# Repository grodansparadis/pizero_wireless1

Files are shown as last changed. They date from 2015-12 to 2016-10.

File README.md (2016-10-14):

<h1>Pizero Wireless 1 HAT</h1>

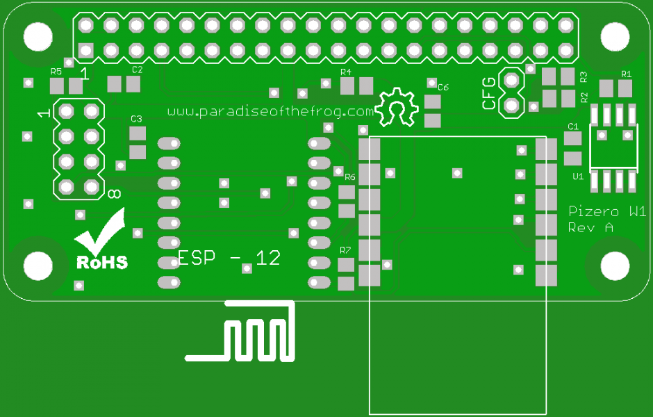
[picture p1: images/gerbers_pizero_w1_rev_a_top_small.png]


The Pizero Wireless 1 HAT is a PCB module that can host either

<ul>
<li>One nrf24L10 wireless tranceiver.</li>
<li>One Microchip MV24J40A/B IEEE 802.11.14 tranceiver module.</li>
<li>One ESP8288 WiFi module.</li>
</ul>

You can order the module from the <a href="http://www.frogshop.se">FrogShop</a>.

<hr>

This project is licensed under the 
<a href="http://creativecommons.org/licenses/by-nc-sa/3.0/">Creative Commons open source license Attribution-NonCommercial-ShareAlike 3.0 Unported</a>. 
Other license options are available by conacting <a href="malto:info@grodansparadis.com">Paradis of the Frog AB</a>

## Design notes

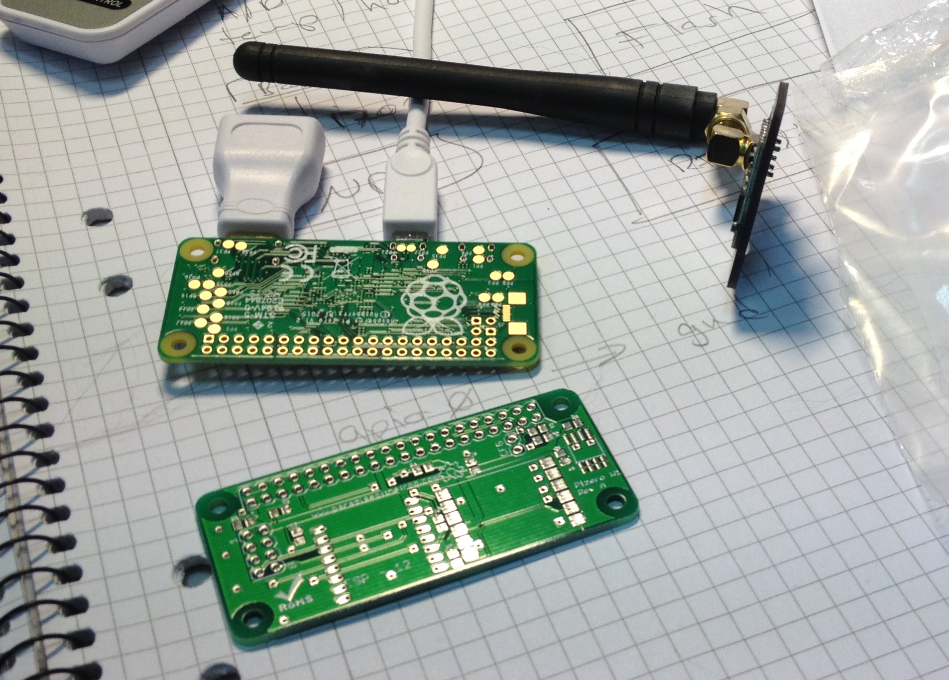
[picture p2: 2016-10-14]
images/prototype_arrival.png

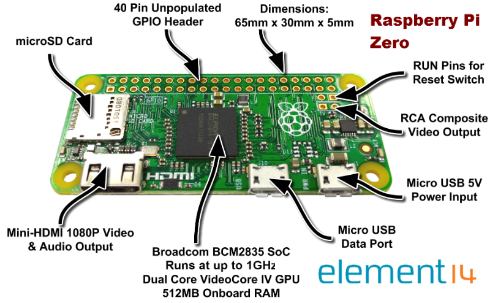
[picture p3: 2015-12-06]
docs/Pi+Zero+Features+Graphic+-+Small.png

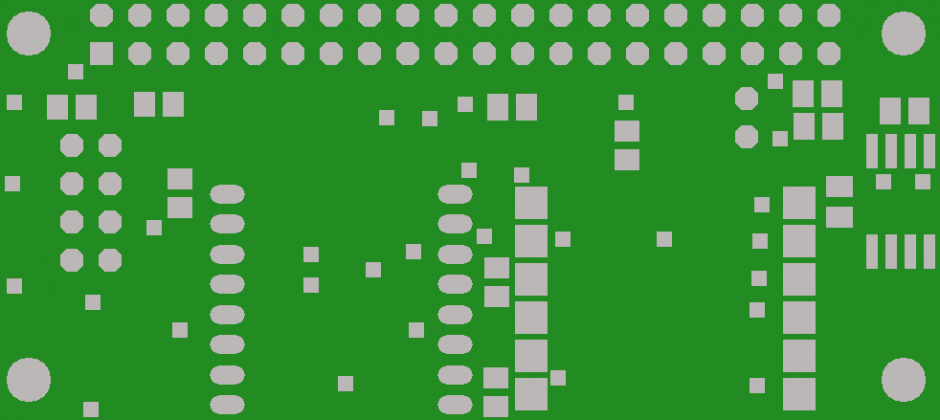
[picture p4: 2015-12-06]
images/gerbers_pizero_w1_rev_a_gts_small.png

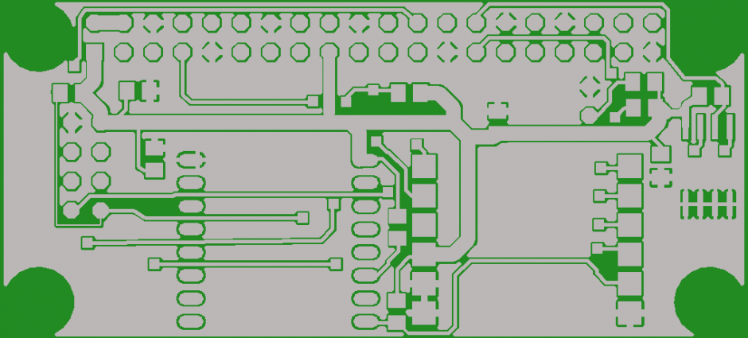
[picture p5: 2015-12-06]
images/gerbers_pizero_w1_rev_a_gtl_small.png

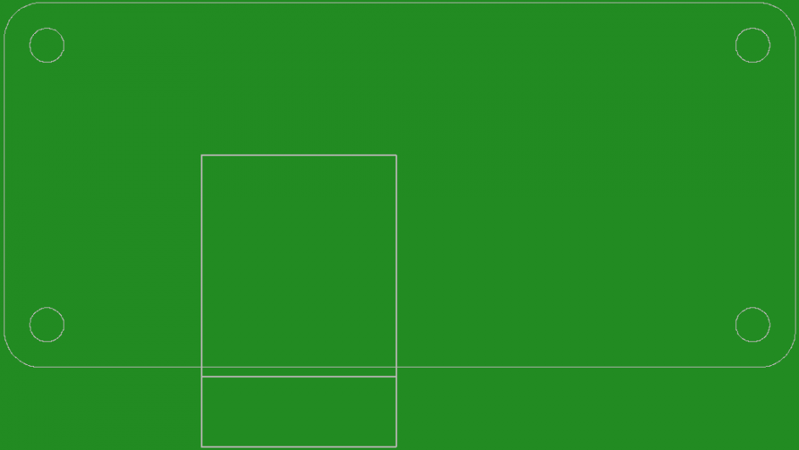
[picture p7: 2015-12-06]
images/gerbers_pizero_w1_rev_a_gbo_small.png

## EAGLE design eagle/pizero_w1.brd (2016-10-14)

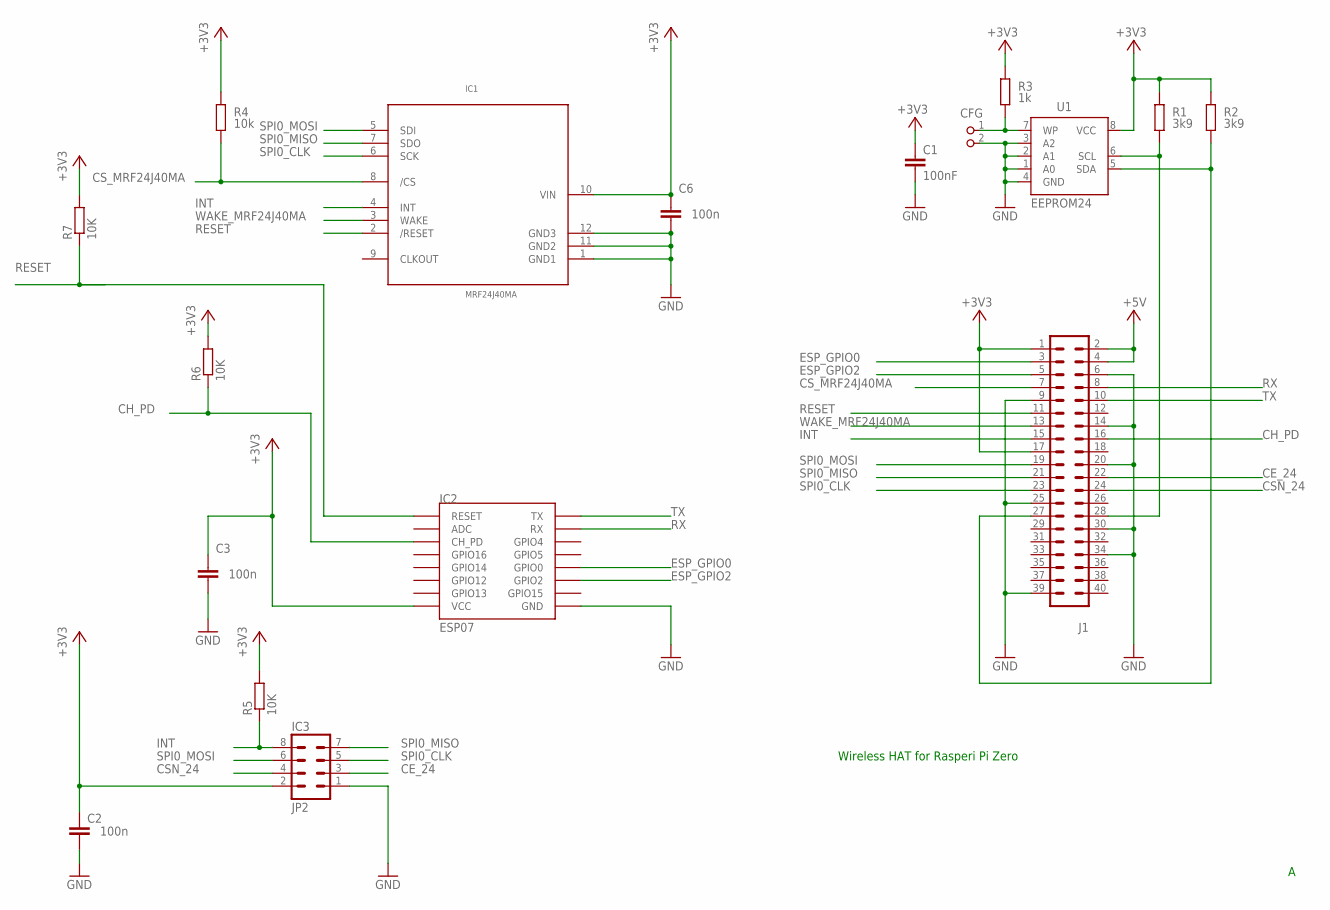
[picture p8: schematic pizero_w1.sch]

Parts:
C1: 100nF; C0805K
C2, C3, C6: 100n; C0805
CFG: PIN2_100; PIN_W_2
IC1: MRF24J40MA
IC2: ESP07; ESP12
IC3: JP2; MA04-2
J1: PIZERO_THROUGH_HOLE; PIZERO_THOUGH_HOLE
R1, R2: 3k9; M0805; TOLERANCE 5%
R3: 1k; M0805; TOLERANCE 5%
R4: 10k; M0805; TOLERANCE 5%
R5, R6, R7: 10K; R0805
U1: EEPROM24; SOIC8

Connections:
+3V3: C1.1, C2.1, C3.1, C6.1, IC1.10 (VIN), IC2.VCC, IC3.2, J1.1, J1.17, R1.2, R2.2, R3.2, R4.2, R5.2, R6.2, R7.2, U1.8 (VCC)
+5V: J1.2, J1.4
CE_24: IC3.3, J1.22
CH_PD: IC2.CH_PD, J1.16, R6.1
CSN_24: IC3.4, J1.24
CS_MRF24J40MA: IC1.8 (/CS), J1.7, R4.1
ESP_GPIO0: IC2.GPIO0, J1.3
ESP_GPIO2: IC2.GPIO2, J1.5
GND: C1.2, C2.2, C3.2, C6.2, CFG.2, IC1.1 (GND1), IC1.11 (GND2), IC1.12 (GND3), IC2.GND, IC3.1, J1.6, J1.9, J1.14, J1.20, J1.25, J1.30, J1.34, J1.39, U1.1 (A0), U1.2 (A1), U1.3 (A2), U1.4 (GND)
INT: IC1.4 (INT), IC3.8, J1.15, R5.1
unnamed: CFG.1, R3.1, U1.7 (WP)
RESET: IC1.2 (/RESET), IC2.RESET, J1.11, R7.1
RX: IC2.RX, J1.8
SCL: J1.28, R1.1, U1.6 (SCL)
SDA: J1.27, R2.1, U1.5 (SDA)
SPI0_CLK: IC1.6 (SCK), IC3.5, J1.23
SPI0_MISO: IC1.7 (SDO), IC3.7, J1.21
SPI0_MOSI: IC1.5 (SDI), IC3.6, J1.19
TX: IC2.TX, J1.10
WAKE_MRF24J40MA: IC1.3 (WAKE), J1.13

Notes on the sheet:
Wireless HAT for Rasperi Pi Zero

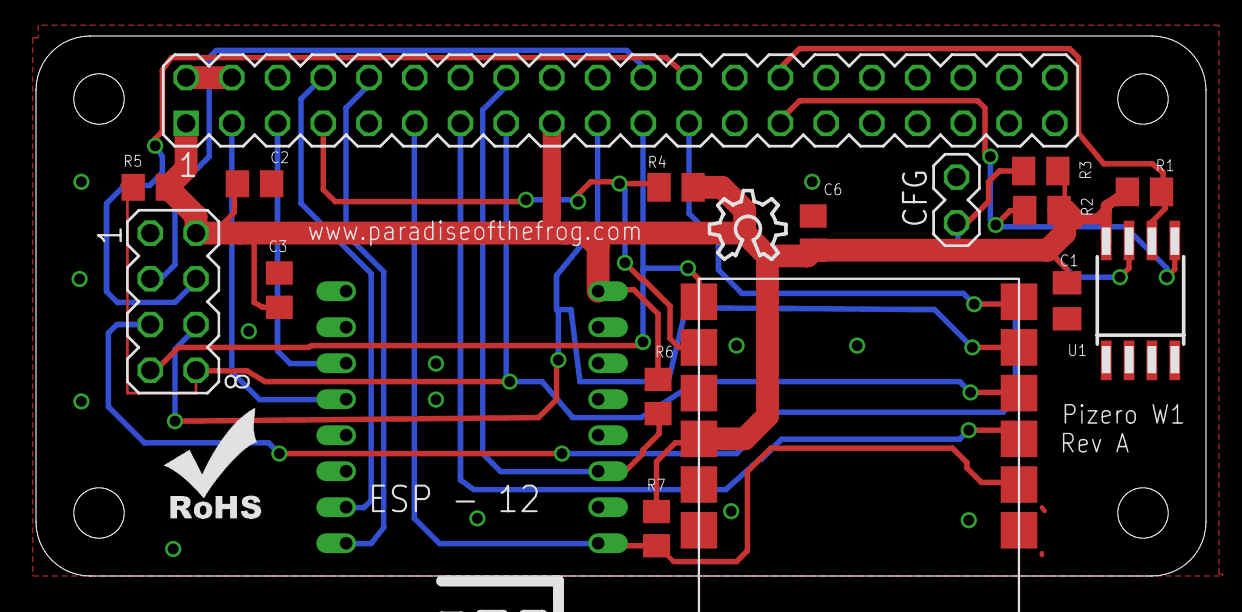
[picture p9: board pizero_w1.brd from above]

Board: 2 copper layers, 65.0 x 30.0 mm, 19 parts (0 on the bottom side), 20 nets.

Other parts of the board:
U$1: OSHW_8X150_NOTEXT
U$2: ROHS_SILK

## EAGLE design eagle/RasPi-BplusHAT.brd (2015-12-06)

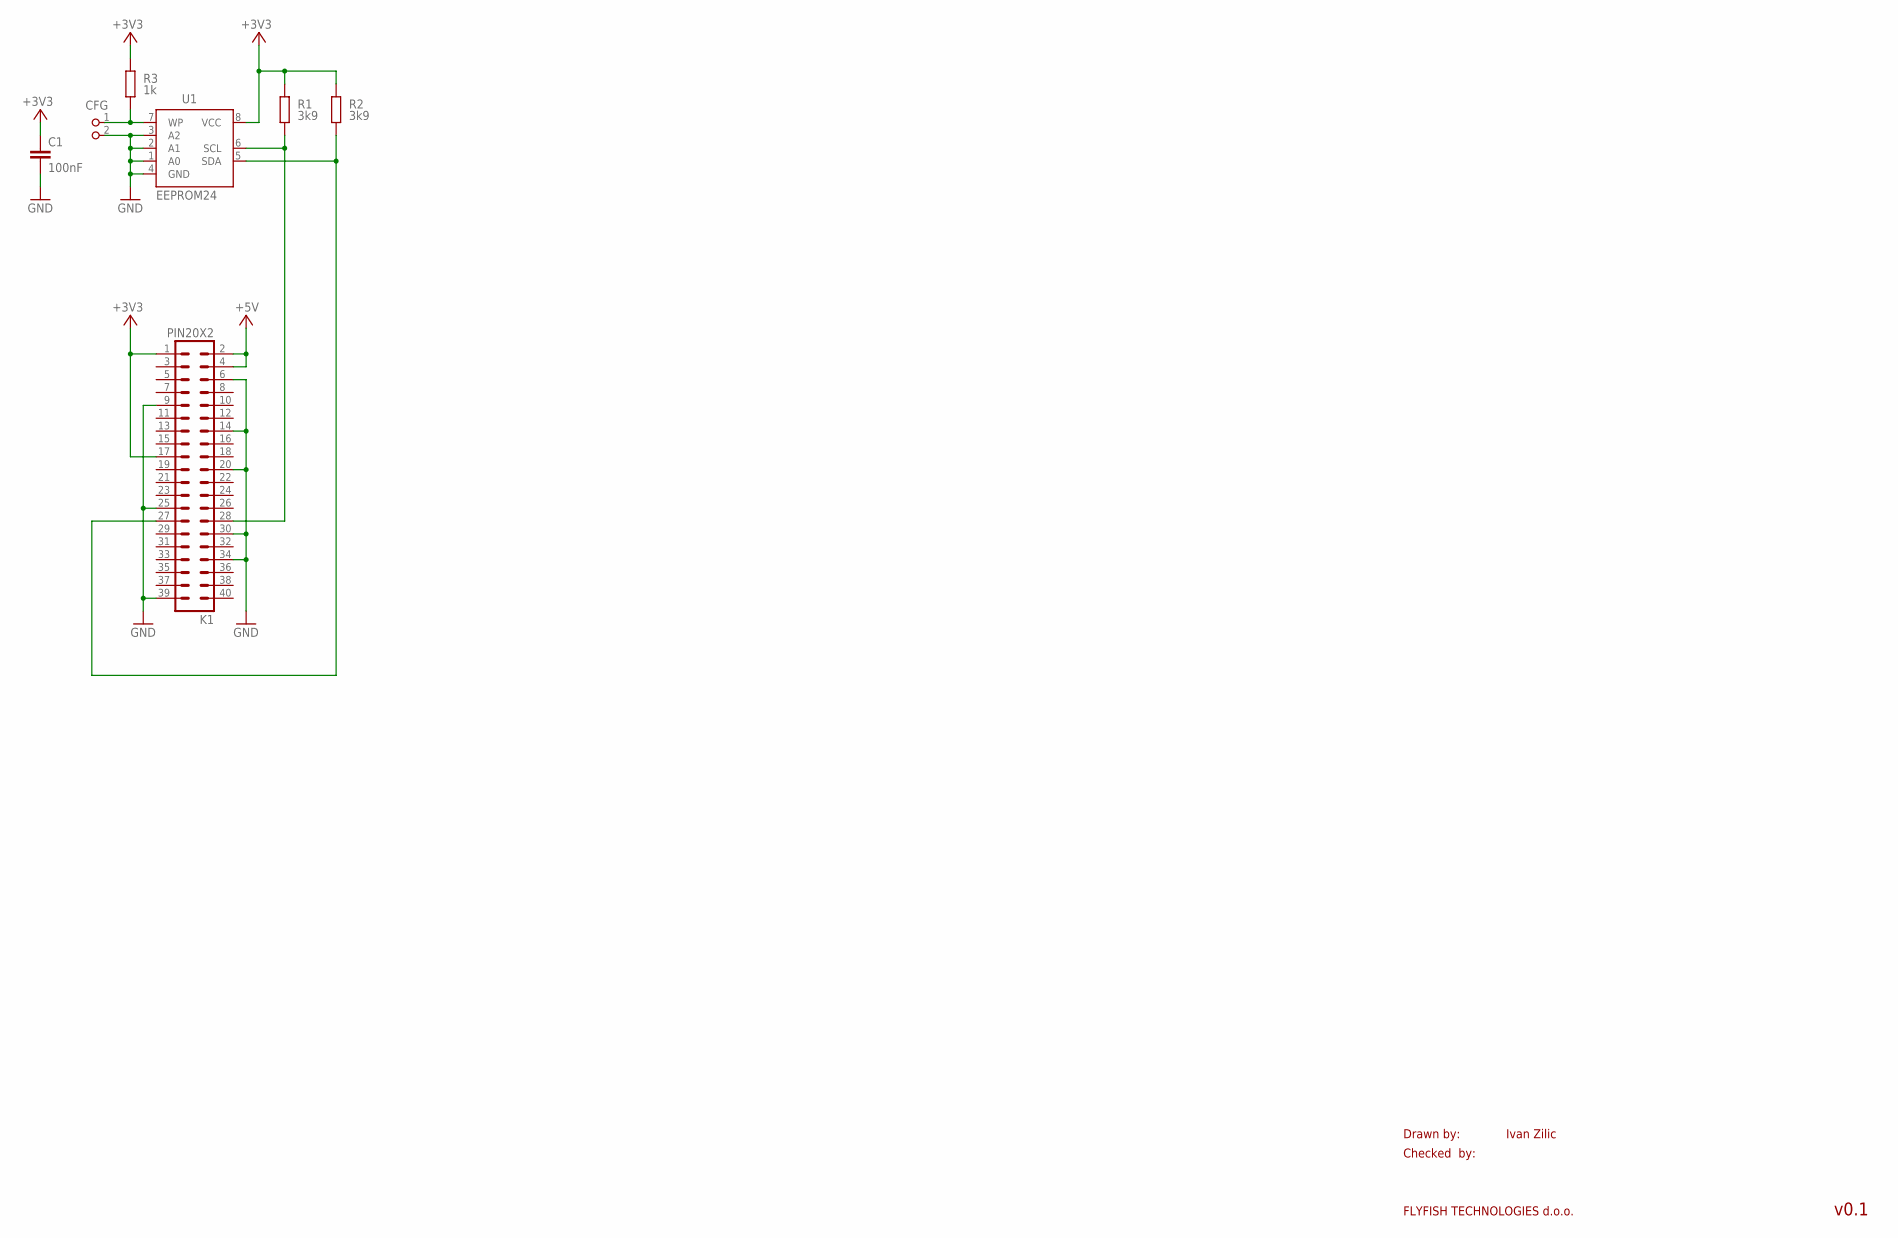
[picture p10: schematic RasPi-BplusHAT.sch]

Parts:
C1: 100nF; C0805K
CFG: PIN2_100; PIN_W_2
K1: PIN20X2; PIN_20X2
R1, R2: 3k9; M0805; TOLERANCE 5%
R3: 1k; M0805; TOLERANCE 5%
U1: EEPROM24; SOIC8

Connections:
+3V3: C1.1, K1.1, K1.17, R1.2, R2.2, R3.2, U1.8 (VCC)
+5V: K1.2, K1.4
GND: C1.2, CFG.2, K1.6, K1.9, K1.14, K1.20, K1.25, K1.30, K1.34, K1.39, U1.1 (A0), U1.2 (A1), U1.3 (A2), U1.4 (GND)
unnamed: K1.28, R1.1, U1.6 (SCL)
unnamed: K1.27, R2.1, U1.5 (SDA)
unnamed: CFG.1, R3.1, U1.7 (WP)

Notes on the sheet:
Drawn by:
Checked by:
FLYFISH TECHNOLOGIES d.o.o.
Ivan Zilic
v0.1

Board: 2 copper layers, 7 parts (0 on the bottom side), 6 nets, no tracks yet.

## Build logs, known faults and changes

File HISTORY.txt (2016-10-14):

Pizero Wireless 1 HAT
=====================

2015-12-06 AKHE - Started project

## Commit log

2015-12-06 Initial checkin
    [RasPi-BplusHAT.brd, RasPi-BplusHAT.sch, RasPi-BplusHAT_CamSlot.brd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]
2015-12-06 Added pcb picture
2016-10-14 Edited componet texts
    [pizero_w1.brd]
